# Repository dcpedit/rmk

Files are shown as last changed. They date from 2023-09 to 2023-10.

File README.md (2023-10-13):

rmk-wide-1

# r/mk keyboard

The r/mk is a "keyboard" that mimics the style of the r/mk stickers that are floating around out there.

I got the idea of using plate mount MX stabalizers to go with the Choc v2 switch from Gimbal in this post:
https://www.keebtalk.com/t/new-kailh-choc-v2-switches/8349/22

If you use MX switches, you will need to use a plate with plate mount stabs, or skip the stabs altogether.

The switch footprints are from this project: https://github.com/luke-schutt/Pi5Keyboard. They support Kailh Choc V1, V2, Gateron low profile, and MX switches

And finally, the schematic and wiring for the rp2040 was taken from this project: https://github.com/Sleepdealr/RP2040-designguide

## Layout and pics

[Keyboard Layout Editor (KLE) link](http://www.keyboard-layout-editor.com/#/gists/66ec27985efc342d9c4acf2d43243eb4)

[Image gallery](https://imgur.com/a/in2jYlU)
## Stabalizer installation for Choc v2 switches

The installation of the stab wire is a bit tricky since it needs to go under the PCB.  This is the procedure I followed.

First, snap the stabalizer housing into the PCB without the stem or wire assembled.



Next, insert the stems into the housing.



Finally, you'll need to squeeze the wire in between the PCB and plastic "clip" so that it can be pushed into place.  You may need to lift the clip with a flat tool to create a gap, and apply a bit of force to get the wire in place.



## Case assembly

| Part | Count | Notes |
|---|---|---|
| 3mm acrylic | 6 |
| Acrylic cement | 1 | [Link](https://a.co/d/a8NEyjm)
| 1.5mm double-sided foam tape| 1 |
| Thin double-sided tape | 1 | [Link](https://a.co/d/aWlYKNr)
| Adhesive rubber feet | 4 | [Link](https://www.etsy.com/listing/1327182543/vath-self-adhesive-silicone-rubber-feet)

The case featured in the photo is made of 6 layers of 3mm acrylic glued together.  You'll need to cut all 6 layers numbered #1 through #6 in the `case.ai` Illustrator file in the `assets` folder.  I used Choc v2 low profile switches for this build, but if you use taller switches (ex Cherry MX), you may want to add an extra `#2 Top spacer` layer to hide the gap.

1) Glue layers #1 through #5 together with acrylic glue of your choice (I use Weld-On).  
2) Cut 2 squares of foam tape and place them on the PCB where the corner blockers are.  Make sure the tape is completely hidden by the blockers.
3) Stick the PCB to the top of the case, pushing down on the area where the foam tape is.
4) Cut strips of the thin double sided tape and place them around the bottom edge of the case.
5) Line up the bottom layer (#6) and press it into place.
6) Place the rubber feet in each corner of the bottom of the case.

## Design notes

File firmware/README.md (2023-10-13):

# Vial Firmware

You can download the `dcpedit_rmk_vial.uf2` binary and flash the PCB directly.

Source code can be viewed here: https://github.com/dcpedit/vial-qmk/tree/rmk/keyboards/dcpedit/rmk

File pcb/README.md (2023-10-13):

# rmk (r/mk) PCB




You can use the files in the `production` folder for JLCPCB

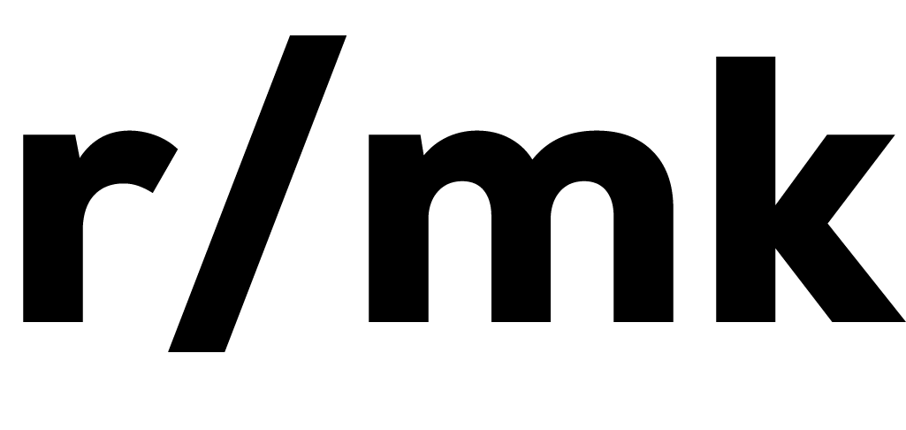
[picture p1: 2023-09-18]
assets/rmk_logo.png

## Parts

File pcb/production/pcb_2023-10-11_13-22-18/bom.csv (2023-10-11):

Designator | Footprint | Quantity | Value | LCSC Part #
C1, C10, C11, C12, C13, C14, C15, C5, C6, C9 | 0402 | 10 | 100nF | C1525
C16, C17, C4, C8 | 0402 | 4 | 1uF | C52923
C2, C3 | 0402 | 2 | 22pF | C1555
C7 | 0402 | 1 | 10uF | C15525
D1, D10, D2, D3, D4, D5, D6, D7, D8, D9 | D_SOD-123 | 10 | D | C81598
F1 | 1206 | 1 | 500mA | C70076
J1 | USB_C_Receptacle_HRO_TYPE-C-31-M-12 | 1 | USB_C_Receptacle_USB2.0 | C165948
MX1, MX10, MX2, MX3, MX4, MX5, MX6, MX6.175, MX7, MX8, MX9 | Low Profile GC plus MX | 11 | MX-NoLED
R1, R2, R7 | 0402 | 3 | 1k | C11702
R3, R4 | 0402 | 2 | 5k1 | C25905
R5, R6 | 0603 | 2 | 27R | C25190
U1 | SOIC-8_5.23x5.23mm_P1.27mm | 1 | W25Q128JVS | C131025
U2 | SOT-23-6 | 1 | USBLC6-2SC6 | C2827654
U3 | RP2040-QFN-56 | 1 | RP2040 | C2040
U4 | SOT-23 | 1 | XC6206PxxxMR-Regulator_Linear | C5446
Y1 | Crystal_SMD_3225-4Pin_3.2x2.5mm | 1 | 12MHz | C9002

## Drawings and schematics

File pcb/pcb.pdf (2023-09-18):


1 GPIO8 11 GPIO9 12 GPIO10 13 GPIO11 14 GPIO12 15 GPIO13 16 GPIO14 17 GPIO15 18 TESTEN 19 GPIO0 2 XTAL_IN 20 XTAL_OUT 21 SWCLK 24 SWDIO 25 ~{RUN} 26 GPIO16 27 GPIO17 28 GPIO18 29 GPIO1 3 GPIO19 30 GPIO20 31 GPIO21 32 GPIO22 34 GPIO23 35 GPIO24 36 GPIO25 37 GPIO26/ADC0 38 GPIO27/ADC1 39 GPIO2 4 GPIO28/ADC2 40 GPIO29/ADC3 41 ADC_AVDD 43 VREG_VIN 44 VREG_VOUT 45 D- 46 D+ 47 USB_VDD 48 GPIO3 5 DVDD 50 QSPI_SD3 51 QSPI_SCLK 52 QSPI_SD0 53 QSPI_SD2 54 QSPI_SD1 55 QSPI_SS_N 56 GND 57 GPIO4 6 GPIO5 7 GPIO6 8 GPIO7 9 U3 GND RP2040 +3.3V C6

File: RP2040-Guide.kicad_sch Sheet: / Sleepdealer

Id: 1/1 Title: RP2040 - Design Guide

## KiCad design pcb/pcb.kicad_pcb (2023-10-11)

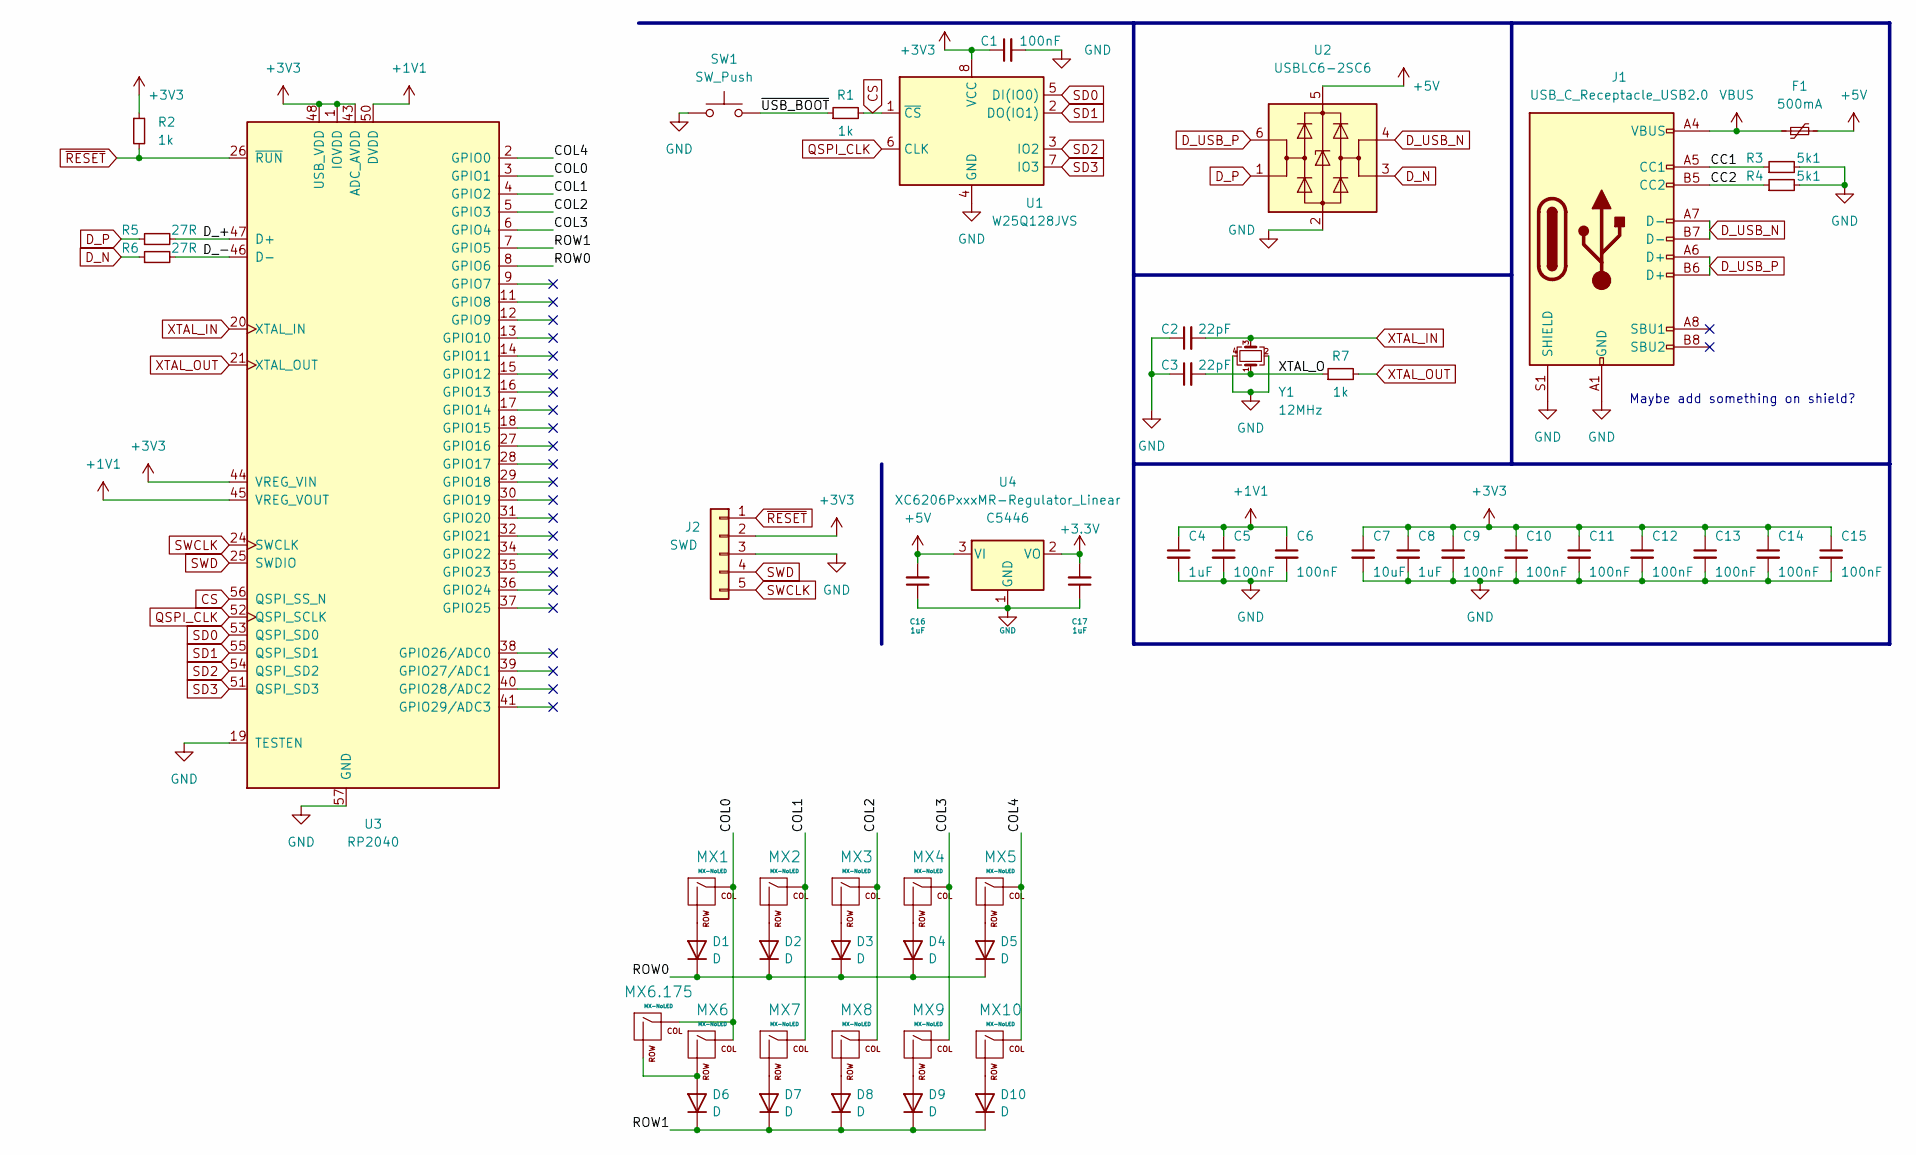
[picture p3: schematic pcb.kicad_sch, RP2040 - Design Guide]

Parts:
C1, C5, C6, C9, C10, C11, C12, C13, C14, C15: 100nF; C_0402_1005Metric; LCSC C1525
C2, C3: 22pF; C_0402_1005Metric; LCSC C1555
C4, C8, C16, C17: 1uF; C_0402_1005Metric; LCSC C52923
C7: 10uF; C_0402_1005Metric; LCSC C15525
D1, D2, D3, D4, D5, D6, D7, D8, D9, D10: D; LCSC C81598
F1: 500mA; Fuse_1206_3216Metric; LCSC C70076
J1: USB_C_Receptacle_USB2.0; USB_C_Receptacle_HRO_TYPE-C-31-M-12; LCSC C165948
J2: SWD; PinSocket_1x05_P2.54mm_Vertical
MX1, MX2, MX3, MX4, MX5, MX6, MX6.175, MX7, MX8, MX9, MX10: MX-NoLED
R1, R2, R7: 1k; R_0402_1005Metric; LCSC C11702
R3, R4: 5k1; R_0402_1005Metric; LCSC C25905
R5, R6: 27R; R_0603_1608Metric; LCSC C25190
SW1: SW_Push; PinSocket_1x02_P2.54mm_Vertical
U1: W25Q128JVS; SOIC-8_5.23x5.23mm_P1.27mm; LCSC C131025
U2: USBLC6-2SC6; SOT-23-6; LCSC C2827654
U3: RP2040; RP2040-QFN-56; LCSC C2040
U4: XC6206PxxxMR-Regulator_Linear; SOT-23; LCSC C5446
Y1: 12MHz; Crystal_SMD_3225-4Pin_3.2x2.5mm; LCSC C9002

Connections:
+1V1: C4.1, C5.1, C6.1, U3.23 (DVDD), U3.45 (VREG_VOUT), U3.50 (DVDD)
+5V: C16.2, F1.2, U2.5 (VBUS), U4.3 (VI)
/CC1: J1.A5 (CC1), R3.1
/CC2: J1.B5 (CC2), R4.1
/COL0: MX1.1 (COL), MX6.1 (COL), MX6.175.1 (COL), U3.3 (GPIO1)
/COL1: MX2.1 (COL), MX7.1 (COL), U3.4 (GPIO2)
/COL2: MX3.1 (COL), MX8.1 (COL), U3.5 (GPIO3)
/COL3: MX4.1 (COL), MX9.1 (COL), U3.6 (GPIO4)
/COL4: MX5.1 (COL), MX10.1 (COL), U3.2 (GPIO0)
/D_+: R5.2, U3.47 (D+)
/D_-: R6.2, U3.46 (D-)
/ROW0: D1.1 (K), D2.1 (K), D3.1 (K), D4.1 (K), D5.1 (K), U3.8 (GPIO6)
/ROW1: D6.1 (K), D7.1 (K), D8.1 (K), D9.1 (K), D10.1 (K), U3.7 (GPIO5)
/XTAL_O: C3.2, R7.1, Y1.1
/~USB_BOOT: R1.1, SW1.2
CS: R1.2, U1.1 (~CS), U3.56 (QSPI_SS_N)
D_N: R6.1, U2.3 (I/O2)
D_P: R5.1, U2.1 (I/O1)
D_USB_N: J1.A7 (D-), J1.B7 (D-), U2.4 (I/O2)
D_USB_P: J1.A6 (D+), J1.B6 (D+), U2.6 (I/O1)
GND: C1.2, C2.1, C3.1, C4.2, C5.2, C6.2, C7.2, C8.2, C9.2, C10.2, C11.2, C12.2, C13.2, C14.2, C15.2, C16.1, C17.1, J1.A1 (GND), J1.A12 (GND), J1.B1 (GND), J1.B12 (GND), J1.S1 (SHIELD), J2.3, R3.2, R4.2, SW1.1, U1.4 (GND), U2.2 (GND), U3.19 (TESTEN), U3.57 (GND), U4.1 (GND), Y1.2, Y1.4
unnamed: D1.2 (A), MX1.2 (ROW)
unnamed: D2.2 (A), MX2.2 (ROW)
unnamed: D3.2 (A), MX3.2 (ROW)
unnamed: D4.2 (A), MX4.2 (ROW)
unnamed: D5.2 (A), MX5.2 (ROW)
unnamed: D6.2 (A), MX6.2 (ROW), MX6.175.2 (ROW)
unnamed: D7.2 (A), MX7.2 (ROW)
unnamed: D8.2 (A), MX8.2 (ROW)
unnamed: D9.2 (A), MX9.2 (ROW)
unnamed: D10.2 (A), MX10.2 (ROW)
QSPI_CLK: U1.6 (CLK), U3.52 (QSPI_SCLK)
SD0: U1.5 (DI(IO0)), U3.53 (QSPI_SD0)
SD1: U1.2 (DO(IO1)), U3.55 (QSPI_SD1)
SD2: U1.3 (IO2), U3.54 (QSPI_SD2)
SD3: U1.7 (IO3), U3.51 (QSPI_SD3)
SWCLK: J2.5, U3.24 (SWCLK)
SWD: J2.4, U3.25 (SWDIO)
VBUS: F1.1, J1.A4 (VBUS), J1.A9 (VBUS), J1.B4 (VBUS), J1.B9 (VBUS)
XTAL_IN: C2.2, U3.20 (XTAL_IN), Y1.3
XTAL_OUT: R7.2, U3.21 (XTAL_OUT)
~RESET: J2.1, R2.2, U3.26 (~RUN)

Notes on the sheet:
Maybe add something on shield?

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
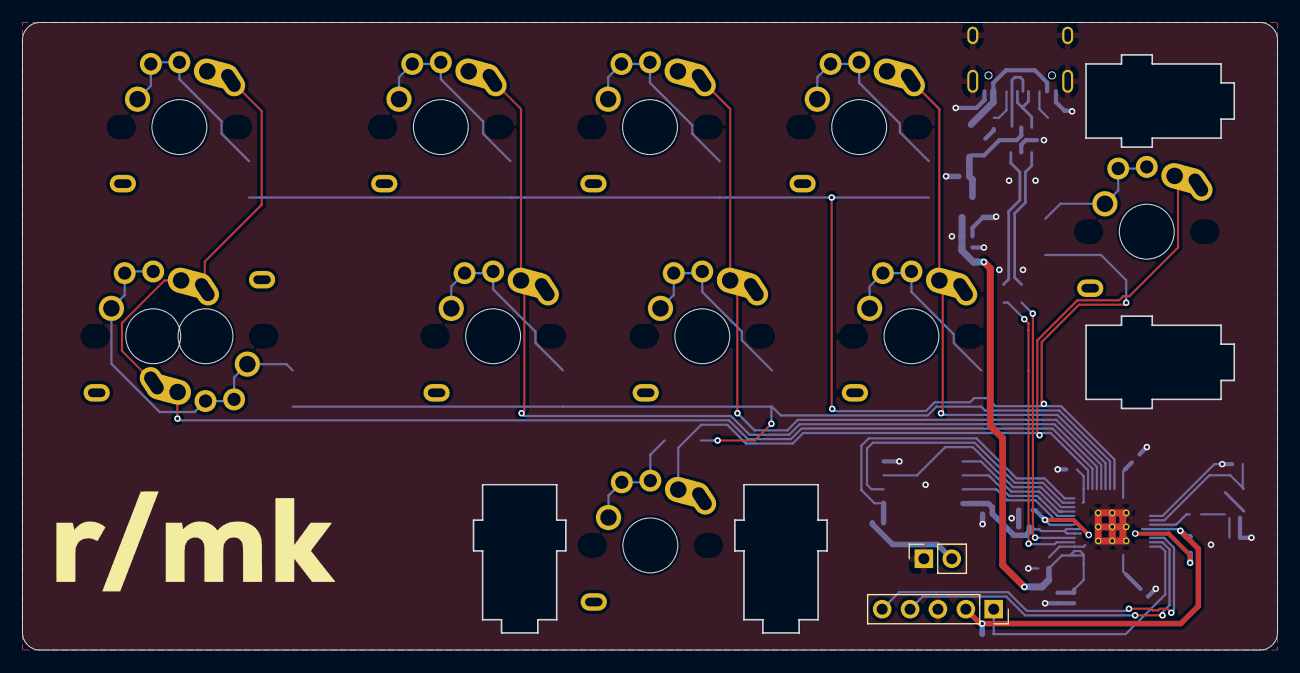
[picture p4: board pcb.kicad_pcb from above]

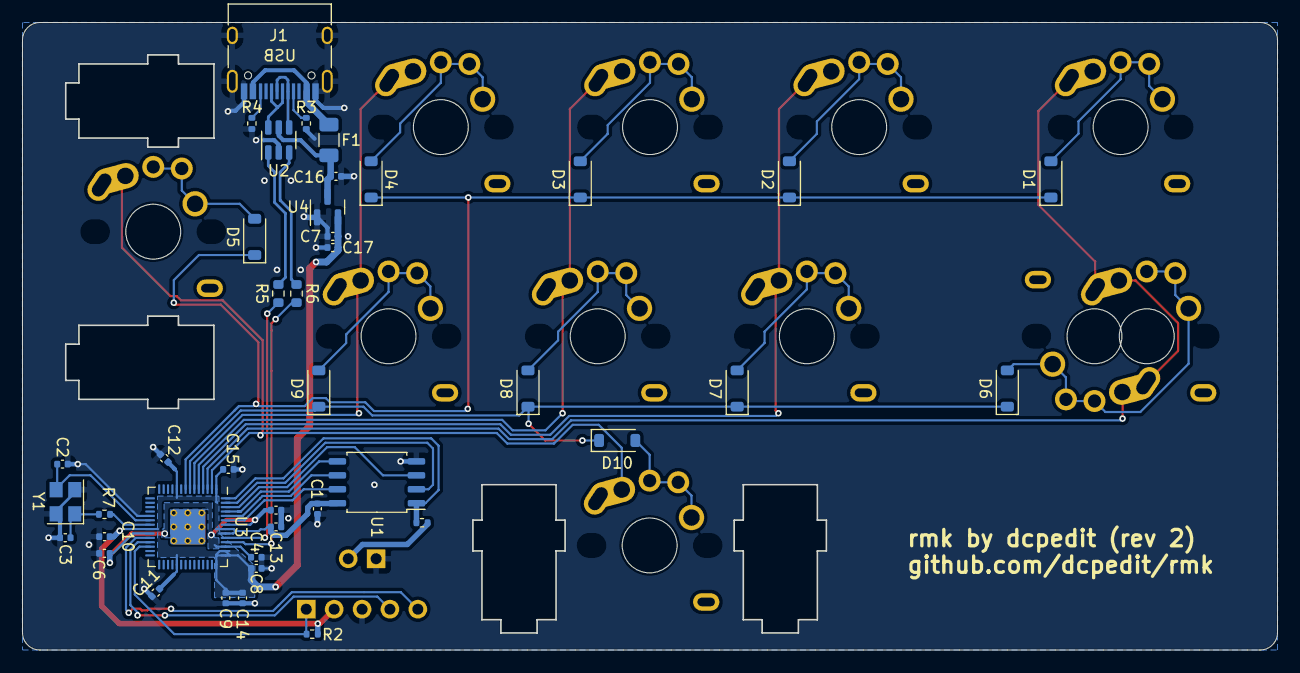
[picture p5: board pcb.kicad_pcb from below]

Board: 2 copper layers, 114.3 x 57.2 mm, 54 parts (41 on the bottom side), 43 nets.

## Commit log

2023-10-11 Add firmware and PCB readme
    [bom.csv, designators.csv, pcb.kicad_pcb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]
2023-10-13 Add pcb step file
